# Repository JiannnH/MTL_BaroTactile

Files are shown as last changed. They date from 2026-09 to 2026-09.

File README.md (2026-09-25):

# MTL_BaroTactile

**A cost-efficient, repairable barometric tactile sensor**





<p align="center">
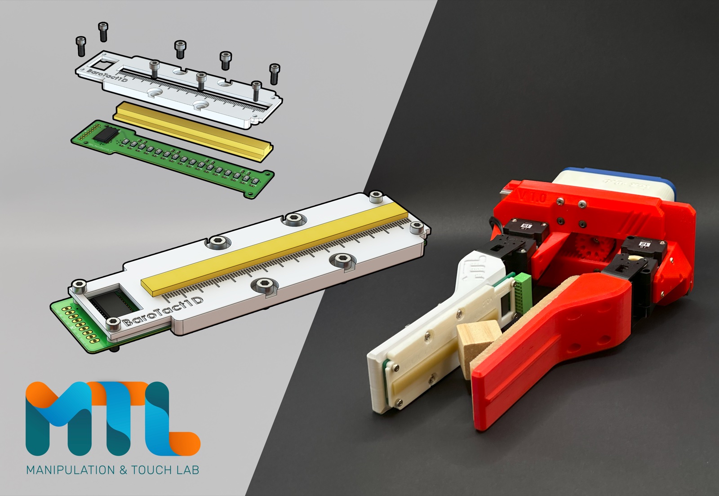
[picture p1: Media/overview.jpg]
BaroTact1D sensor exploded view and the sensor mounted on the E-TRoll gripper
  
</p>

## Highlights

- **Low cost:** material cost below **80 USD**, built from 16 MPL3115A2 MEMS barometers on a single PCB.
- **Repairable:** the rubber layer is molded **separately** rather than over the barometers, then clamped on by a 3D-printed frame, so a worn surface can be swapped in minutes.

## Sensor Design

<p align="center">
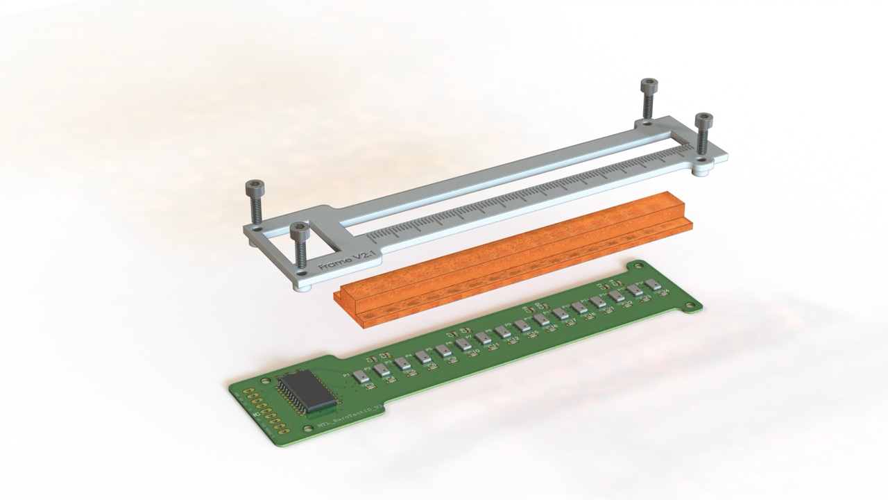
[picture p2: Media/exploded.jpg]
Exploded view: frame, rubber, PCB
  
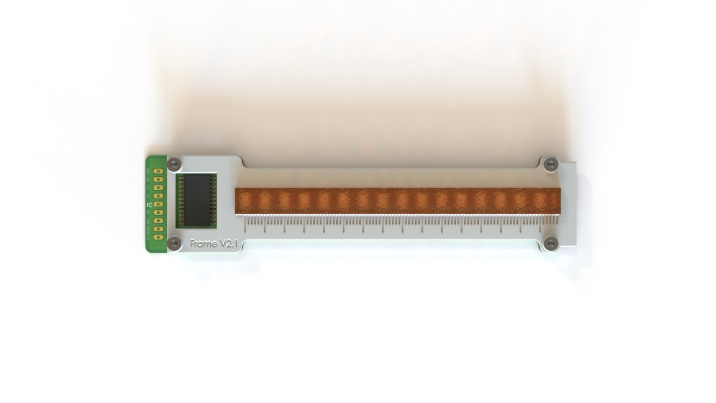
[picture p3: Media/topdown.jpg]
Top-down view of the assembled sensor
  
</p>

The sensor has three layers:

1. **PCB**: 16 MPL3115A2 barometers in a 1D array, read through a multiplexer.
2. **Rubber**: a VytaFlex 40 strip cast in a 3D-printed mold.
3. **Frame**: a 3D-printed clamp bolted to the PCB that holds the rubber in place.

## Demo: Real-Time Localization on the E-TRoll Gripper

<p align="center">
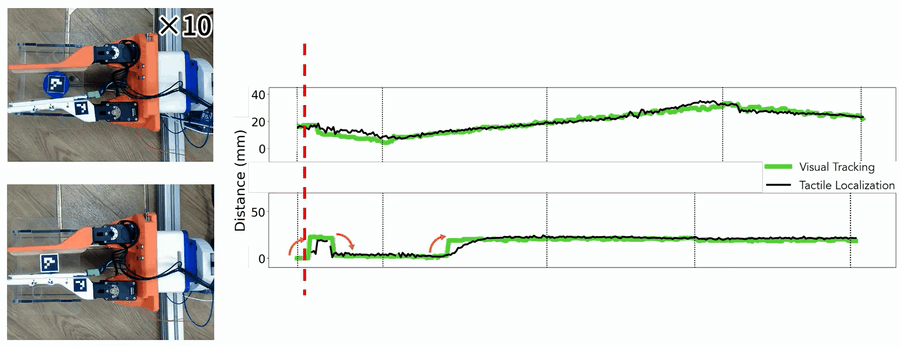
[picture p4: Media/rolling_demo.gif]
Real-time rolling experiment: tactile localization vs visual tracking
  
</p>

The sensor is mounted on one finger of the open-source
[**E-TRoll gripper**](https://www.imperial.ac.uk/manipulation-touch/open-source/hardware/e-troll/)
from the Manipulation and Touch Lab. The gripper rolls a cube and a cylinder across the
sensing surface, and the tactile estimate (black) closely tracks the camera-based ground truth (green).
The video plays at 10× speed.

## Repository Structure

- **[Code](Code/)**: Arduino code for the sensor (MPL3115A2) and the testing rig
- **[Hardware](Hardware/)**: PCB designs, 3D CAD files and testing rig hardware
  - **[PCB/MTL_BaroTactile_MPL3115A2](Hardware/PCB/MTL_BaroTactile_MPL3115A2/)**: main sensor version (used in the paper)
  - **[PCB/MTL_BaroTactile_MS5840](Hardware/PCB/MTL_BaroTactile_MS5840/)**: alternative version with the MS5840
  - **[Mold](Hardware/Mold/)**: rubber mold and frame CAD for fabrication
  - **[TestingRig](Hardware/TestingRig/)**: automated indentation rig for data collection

## Hardware Versions

### MPL3115A2 Version (Paper Implementation)
The primary sensor design, built with the MPL3115A2 barometric pressure sensor.

### MS5840 Version (Alternative)
An alternative design built with the MS5840 barometer. Use it when the MPL3115A2 is out of stock; it gives comparable performance for barometric tactile sensing.

## Fabrication Overview

1. 3D print the rubber mold and apply mold release spray.
2. Mix parts A and B of Smooth-On VytaFlex 40, de-gas the mixture, and pour it into the mold.
3. Close the mold and let it cure for at least 1 day, then remove the rubber.
4. Reflow-solder the components onto the PCB.
5. Place the rubber on the PCB, then bolt the 3D-printed frame over it until the rubber is held securely.

## Citation

If you use this work in your research, please cite our paper:

```bibtex
@ARTICLE{10770605,
  author={Hou, Jian and Zhou, Xin and Spiers, Adam},
  journal={IEEE Transactions on Robotics},
  title={Location and Orientation Super-Resolution Sensing With a Cost-Efficient and Repairable Barometric Tactile Sensor},
  year={2025},
  volume={41},
  pages={729-741},
  doi={10.1109/TRO.2024.3508315}
}
```

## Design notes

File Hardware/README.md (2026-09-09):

# Hardware Design

This folder contains the hardware design files.

## Folder Structure

The repository is organized into the following folders:

**PCB Design**: This folder contains schematics and layout files for our PCB. *PCB/MTL_BaroTactile_MPL3115A2/MTL_BaroTact1D_V3* is the one we used for super-resolution. *PCB/MTL_BaroTactile_MS5840/MTL_BaroTact1D_V4* is a new PCB design, which uses the MS-5840 barometer instead of the MPL3115A2 (stopped manufacturing).
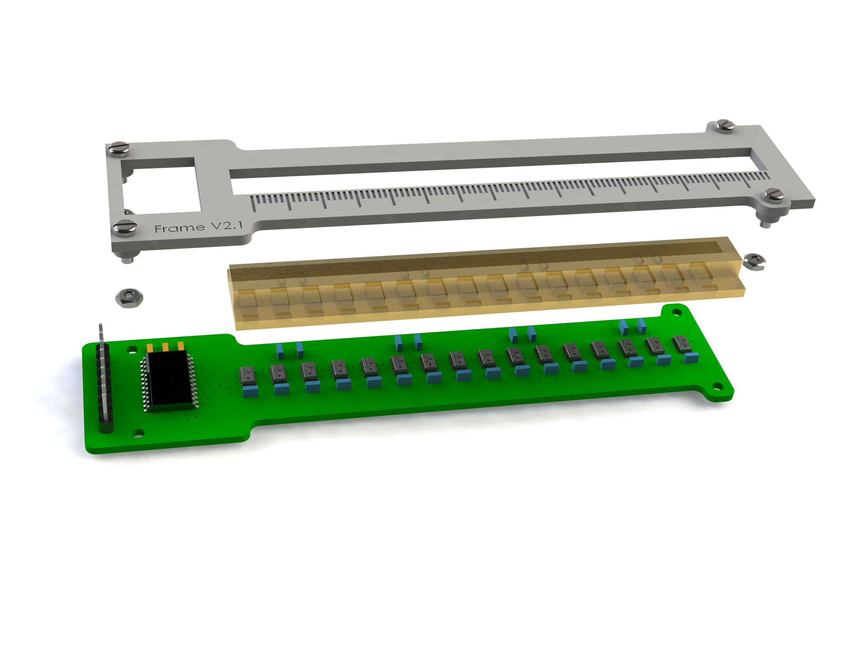
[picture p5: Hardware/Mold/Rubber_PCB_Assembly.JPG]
Sensor Design


**Testing Rig Design**: In this folder, you'll find the 3D-printed components on our testing rig.
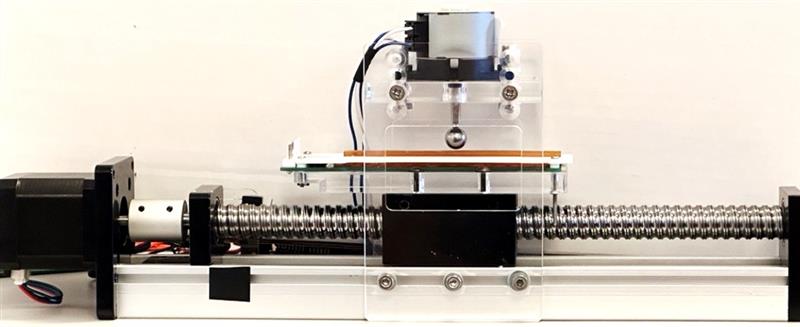
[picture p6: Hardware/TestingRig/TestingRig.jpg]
Testing Rig


**Mold**: This folder contains CAD files related to the mold used in the manufacturing process and assembly method of rubber components and sensors within our hardware.
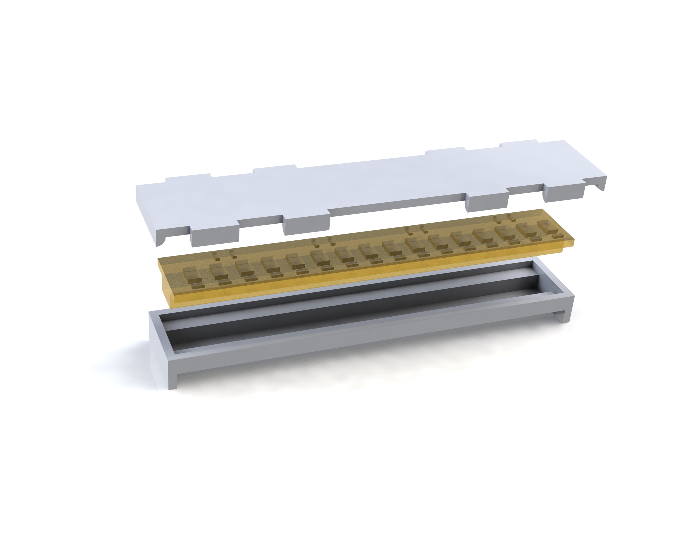
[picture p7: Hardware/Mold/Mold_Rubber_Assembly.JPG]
Mold


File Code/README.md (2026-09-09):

# Firmware

This folder contains the Firmware code for Testing Rig and the Barometric Tactile Sensor.

## Folder Structure

The repository is organized into the following folders:

**Testing_Rig**: Contains the Arduino firmware code for controlling the Testing Rig used in data collection.

**Sensor**: Contains the Arduino firmware code for the Barometric Tactile Sensor, receiving the real-time input for 16 barometers' reading.

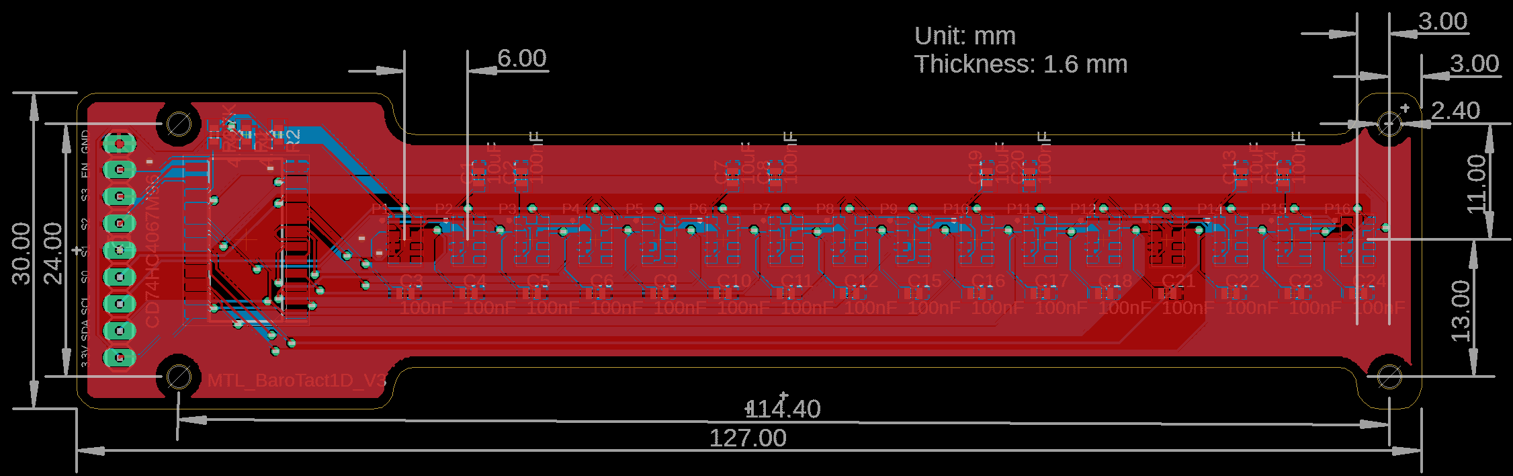
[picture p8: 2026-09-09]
Hardware/PCB/MTL_BaroTactile_MPL3115A2/MTL_BaroTact1D_V3/1D_layout.png

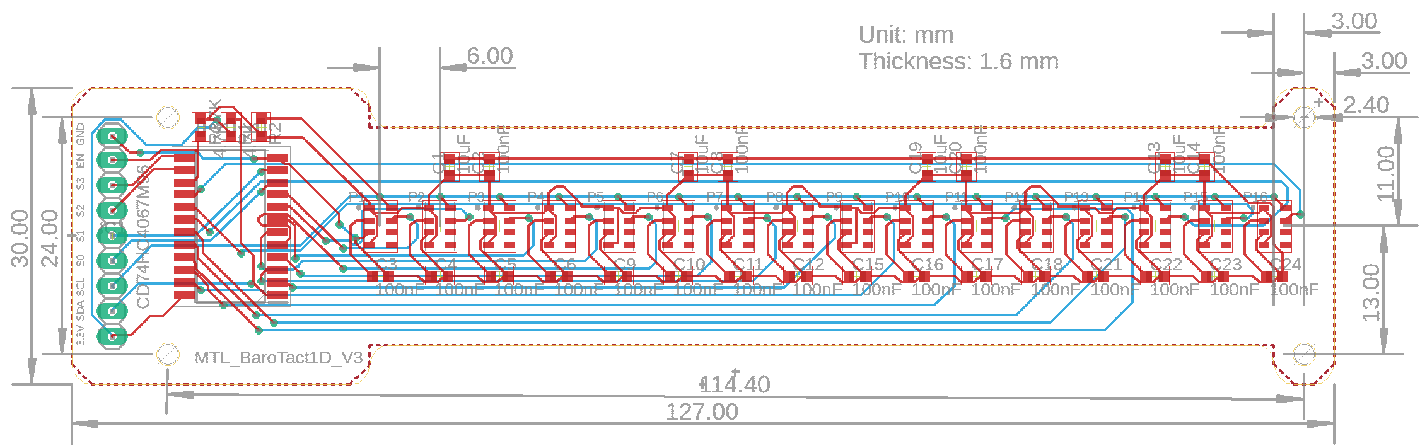
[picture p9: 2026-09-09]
Hardware/PCB/MTL_BaroTactile_MPL3115A2/MTL_BaroTact1D_V3/1D_layout_white.png

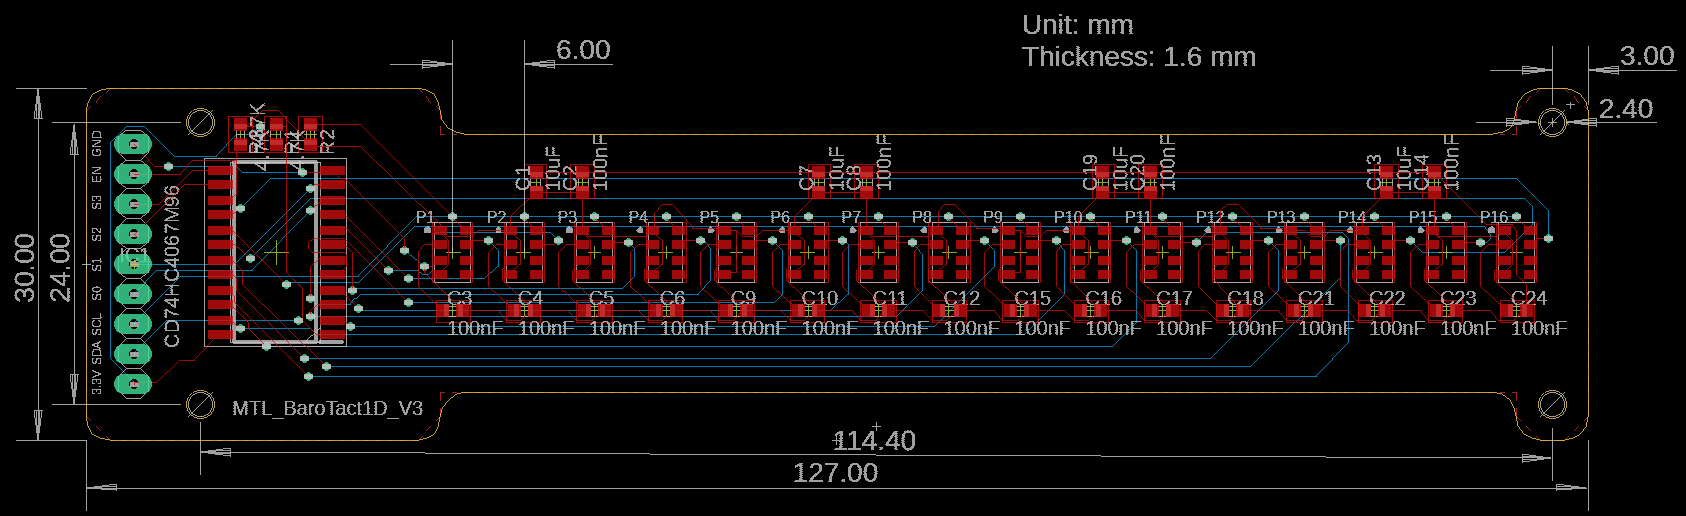
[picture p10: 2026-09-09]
Hardware/PCB/MTL_BaroTactile_MPL3115A2/MTL_BaroTact1D_V3/MTL_Barotact1D_V3.png

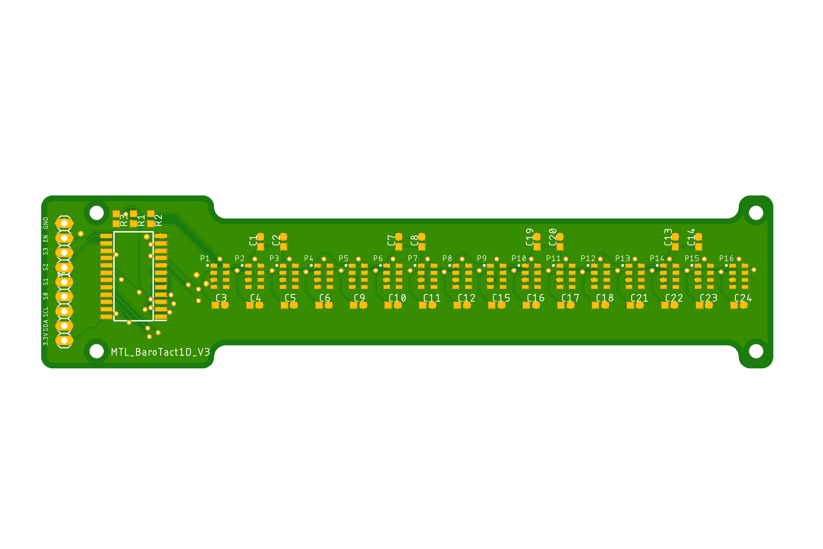
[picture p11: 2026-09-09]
Hardware/PCB/MTL_BaroTactile_MPL3115A2/MTL_BaroTact1D_V3/1D_layout_3D.png

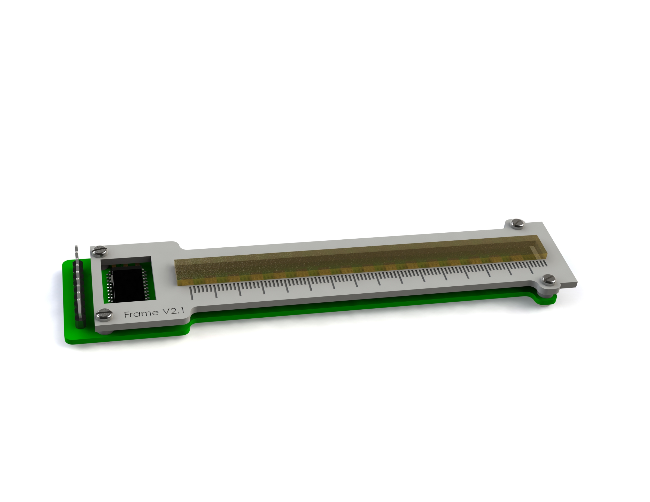
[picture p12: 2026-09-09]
Hardware/Mold/Rubber_PCB_Explode.JPG

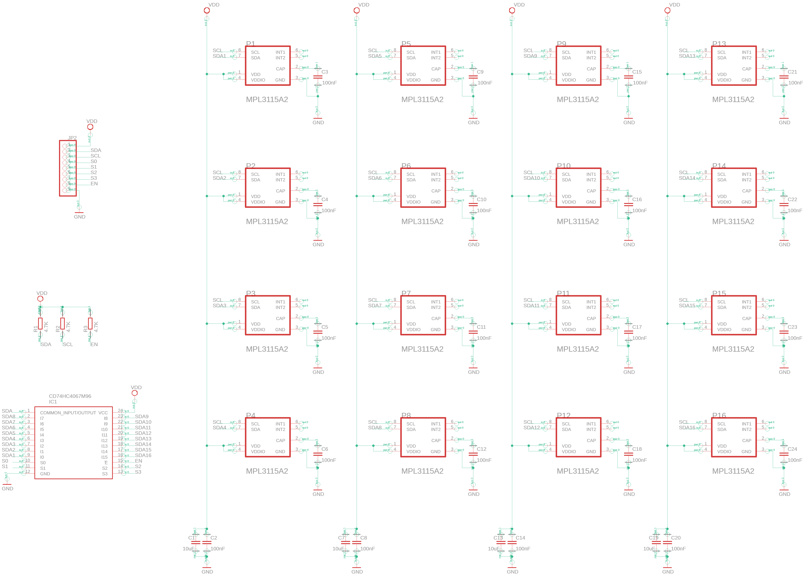
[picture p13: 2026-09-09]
Hardware/PCB/MTL_BaroTactile_MPL3115A2/1D_Sche_img.png

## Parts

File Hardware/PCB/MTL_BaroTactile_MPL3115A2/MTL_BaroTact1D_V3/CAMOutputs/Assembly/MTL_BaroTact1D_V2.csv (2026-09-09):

 |  |  | 1D
Qty | Name | Price(?) | Link | Min order Qty | Note
1 | PINHD-1X9 | 0.647 | https://uk.rs-online.com/web/p/pcb-headers/0453224 | 10 |  | 0.647
1 | CD74HC4067M96 | 0.855 | https://uk.rs-online.com/web/p/multiplexer-demultiplexer-ics/6622577 | 10 |  | 0.855
16 | MPL3115A2 | 8.54 | https://uk.rs-online.com/web/p/pressure-sensor-ics/7500841 | 1 | If ordering 490 pieces or more, the price is ?4.785 | 136.64
1 | 4.7K RR0603 | 0.022 | https://uk.rs-online.com/web/p/thermistor-ics/0110510 | 25 |  | 0.022
1 | 10uF CC0603 | 0.243 | https://uk.rs-online.com/web/p/mlccs-multilayer-ceramic-capacitors/8151377 | 25 |  | 0.243
1 | 100nF CC0603 | 0.243 | https://uk.rs-online.com/web/p/mlccs-multilayer-ceramic-capacitors/8151377 | 25 |  | 0.243
 | Est Price/set | 138.65
 |  |  | 2D
Qty | Name | Price(?) | Link | Min order Qty | Note
1 | PINHD-1X9 | 0.647 | https://uk.rs-online.com/web/p/pcb-headers/0453224 | 10 |  | 0.647
1 | CD74HC4067M96 | 0.855 | https://uk.rs-online.com/web/p/multiplexer-demultiplexer-ics/6622577 | 10 |  | 0.855
16 | MPL3115A2 | 8.54 | https://uk.rs-online.com/web/p/pressure-sensor-ics/7500841 | 1 | If ordering 490 pieces or more, the price is ?4.785 | 136.64
1 | 4.7K RR0603 | 0.022 | https://uk.rs-online.com/web/p/thermistor-ics/0110510 | 25 |  | 0.022
1 | 10uF CC0402 | 0.131 | https://uk.rs-online.com/web/p/mlccs-multilayer-ceramic-capacitors/8467271 | 25 |  | 0.131
1 | 100nF CC0402 | 0.041 | https://uk.rs-online.com/web/p/mlccs-multilayer-ceramic-capacitors/1034089 | 50 |  | 0.041
 | Est Price/set | 138.336

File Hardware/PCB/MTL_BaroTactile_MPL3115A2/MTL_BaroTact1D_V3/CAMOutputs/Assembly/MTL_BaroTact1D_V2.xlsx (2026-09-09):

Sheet: MTL_BaroTact1D_V2
Qty;"Value";"Device";"Package";"Parts";"Description";"CIIVA_IDS";"COMPONENT_LINK_1_DESCRIPTION";"COMPONENT_LINK_1_URL";"COMPONENT_LINK_3_DESCRIPTION";"COMPONENT_LINK_3_URL";"DATASHEET";"DATASHEET_VERSION";"DESCRIPTION";"FOOTPRINT_VARIANT_NAME_0";"FSCL20_PF";"FSCL400_PF";"HEIGHT";"IMPORTED";"IMPORTED_FROM";"IMPORT_TS";"MANUFACTURER_NAME";"MANUFACTURER_PART_NUMBER";"MF";"MOUNTING_TECHNOLOGY";"MOUSER_PART_NUMBER";"MOUSER_PRICE-STOCK";"MPN";"OPERATING_TEMPERATURE_RANGE";"PACKAGE_DESCRIPTION";"PACKAGE_VERSION";"PACKING";"PIN_0_0_7_INSIDE_EDGE";"POPULARITY";"PREFIX";"RELEASE_DATE";"ROHS";"SPICEMODEL";"SPICEPREFIX";"VAULT_GUID";"VAULT_REVISION";"VDD";"VDDIO";
1;"";"PINHD-1X9";"1X09";"JP2";"PIN HEADER";"";"";"";"";"";"";"";"";"";"";"";"";"";"";"";"";"";"";"";"";"";"";"";"";"";"";"";"13";"";"";"";"";"";"";"";"";"";
20;"100nF";"CC0603";"C0603";"C2 | C3 | C4 | C5 | C6 | C8 | C9 | C10 | C11 | C12 | C14 | C15 | C16 | C17 | C18 | C20 | C21 | C22 | C23 | C24";"CAPACITOR | European symbol";"";"";"";"";"";"";"";"";"";"";"";"";"";"";"";"";"";"";"";"";"";"";"";"";"";"";"";"";"";"";"";"NONE";"C";"";"";"";"";
4;"10uF";"CC0603";"C0603";"C1 | C7 | C13 | C19";"CAPACITOR | European symbol";"";"";"";"";"";"";"";"";"";"";"";"";"";"";"";"";"";"";"";"";"";"";"";"";"";"";"";"";"";"";"";"NONE";"C";"";"";"";"";
3;"4.7K";"RR0603";"R0603";"R1 | R2 | R3";"RESISTOR | European symbol";"";"";"";"";"";"";"";"";"";"";"";"";"";"";"";"";"";"";"";"";"";"";"";"";"";"";"";"";"";"";"";"NONE";"R";"";"";"";"";
1;"CD74HC4067M96";"CD74HC4067M96";"SOIC127P1030X265-24N";"IC1";"High Speed CMOS 16-Channel Analog Multiplexer/Demultiplexer";"";"";"";"";"";"";"";"High Speed CMOS 16-Channel Analog Multiplexer/Demultiplexer";"";"";"";"2.65mm";"";"";"";"Texas Instruments";"CD74HC4067M96";"";"";"595-CD74HC4067M96";"https://www.mouser.co.uk/ProductDetail/Texas-Instruments/CD74HC4067M96?qs=xFfolx0DHx0XT7d9xTTZBA%3D%3D";"";"";"";"";"";"";"";"";"";"";"";"";"";"";"";"";
16;"FREESCALE_SEMICONDUCTOR_MPL3115A2FREESCALE_SEMICONDUCTOR_MPL3115A2_0_0";"FREESCALE_SEMICONDUCTOR_MPL3115A2FREESCALE_SEMICONDUCTOR_MPL3115A2_0_0";"FREESCALE_SEMICONDUCTOR_MPL3115A2_0";"P1 | P2 | P3 | P4 | P5 | P6 | P7 | P8 | P9 | P10 | P11 | P12 | P13 | P14 | P15 | P16";"FRES-MPL3115A2-8";"1172243";"Manufacturer URL";"http://www.freescale.com/";"Package Specification";"http://cache.freescale.com/files/shared/doc/package_info/98ASA00260D.pdf";"http://cache.freescale.com/files/sensors/doc/data_sheet/MPL3115A2.pdf";"Rev. 3.0";"";"Manufacturer Recommended";"4 MHz Max.";"400 KHz Max.";"";"yes";"vault";"1521845373";"";"";"Freescale Semiconductor";"Surface Mount";"";"";"MPL3115A2";"-40 to 85 degC";"8-Pin Land Grid Array | Body 5 x 3 mm | Pitch 1.25 mm";"Rev. O";"Tray";"clock";"";"U";"1435138815";"Yes";"";"";"C9CA789F-172F-4FBE-A7EA-5C936E43DE32";"13F1D4E8-B129-4F1C-B772-6A98733F3276";"1.95 to 3.6 V";"1.62 to 3.6 V";

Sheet: Sheet1
1D
Qty | Name | Price(£) | Link | Min order Qty | Note
1 | PINHD-1X9 | 0.647 | https://uk.rs-online.com/web/p/pcb-headers/0453224 | 10 |  | 0.647
1 | Nexperia HEF4067BT | 1.93 | https://uk.rs-online.com/web/p/multiplexer-demultiplexer-ics/0788817 | 1 |  | 1.93
1 | CD74HC4067M96 | 0.855 | https://uk.rs-online.com/web/p/multiplexer-demultiplexer-ics/6622577 | 10 | Currently out of stock | 0.855
16 | MPL3115A2 | 8.54 | https://uk.rs-online.com/web/p/pressure-sensor-ics/7500841 | 1 | If ordering 490 pieces or more, the price is £4.785 | 136.64
3 | 4.7K RR0603 | 0.022 | https://uk.rs-online.com/web/p/thermistor-ics/0110510 | 25 |  | 0.066 | 71-CRCW0603J-4.7K-E3
4 | 10uF CC0603 | 0.243 | https://uk.rs-online.com/web/p/mlccs-multilayer-ceramic-capacitors/8151377 | 25 |  | 0.972 | 581-0603ZW106MAT2A
20 | 100nF CC0603 | 0.243 | https://uk.rs-online.com/web/p/mlccs-multilayer-ceramic-capacitors/8151377 | 25 |  | 4.86 | 581-0603YC104J4T4A
 | Est Price/set | 145.115
2D
Qty | Name | Price(£) | Link | Min order Qty | Note
1 | PINHD-1X9 | 0.647 | https://uk.rs-online.com/web/p/pcb-headers/0453224 | 10 |  | 0.647
1 | Nexperia HEF4067BT | 1.93 | https://uk.rs-online.com/web/p/multiplexer-demultiplexer-ics/0788817 | 1 |  | 1.93
1 | CD74HC4067M96 | 0.855 | https://uk.rs-online.com/web/p/multiplexer-demultiplexer-ics/6622577 | 10 | Currently out of stock | 0.855
16 | MPL3115A2 | 8.54 | https://uk.rs-online.com/web/p/pressure-sensor-ics/7500841 | 1 | If ordering 490 pieces or more, the price is £4.785 | 136.64
3 | 4.7K RR0603 | 0.022 | https://uk.rs-online.com/web/p/thermistor-ics/0110510 | 25 |  | 0.066 | 71-CRCW0603J-4.7K-E3
4 | 10uF CC0402 | 0.131 | https://uk.rs-online.com/web/p/mlccs-multilayer-ceramic-capacitors/8467271 | 25 |  | 0.524 | 581-0402ZD106MAT2A
20 | 100nF CC0402 | 0.041 | https://uk.rs-online.com/web/p/mlccs-multilayer-ceramic-capacitors/1034089 | 50 |  | 0.82 | 581-04023C104KAT2A
 | Est Price/set | 140.627

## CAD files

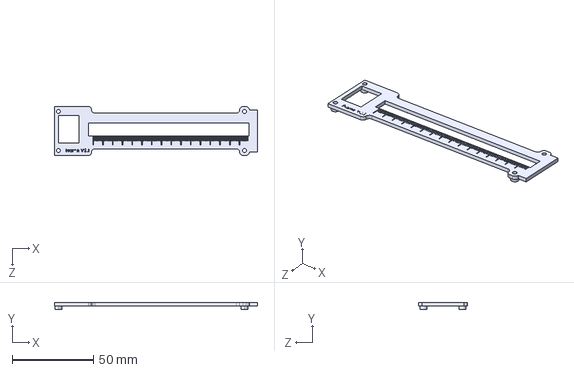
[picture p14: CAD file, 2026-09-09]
Hardware/Mold/frame.STEP
124.8 x 4.00 x 30.0 mm

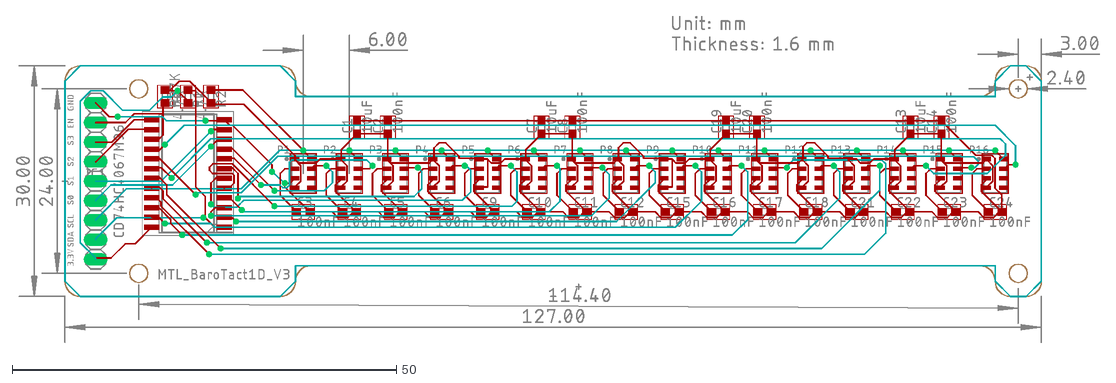
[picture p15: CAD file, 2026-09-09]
Hardware/PCB/MTL_BaroTactile_MPL3115A2/MTL_BaroTact1D_V3/MTL_BaroTact1D_V3.dxf
141.0 x 42.5

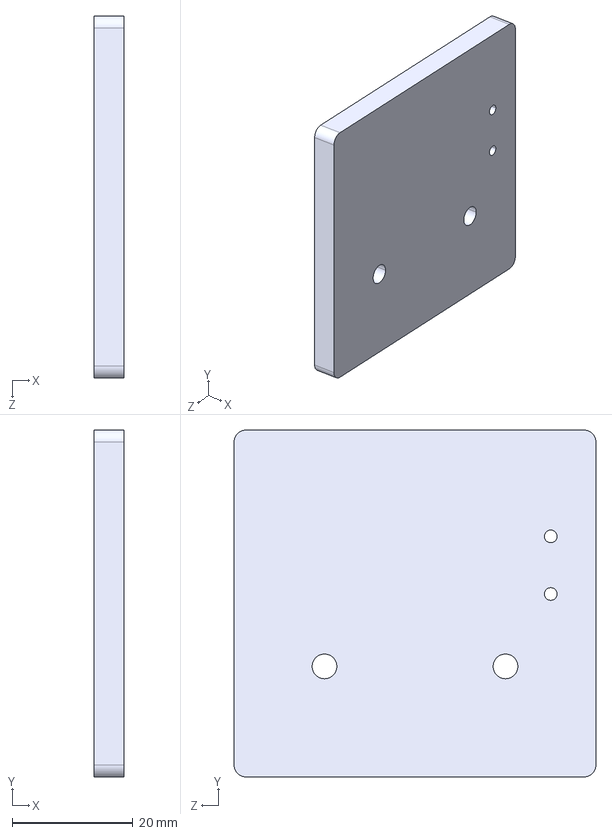
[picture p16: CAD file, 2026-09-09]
Hardware/TestingRig/LimitSwitchMount_V1.STEP
5.00 x 57.5 x 60.0 mm

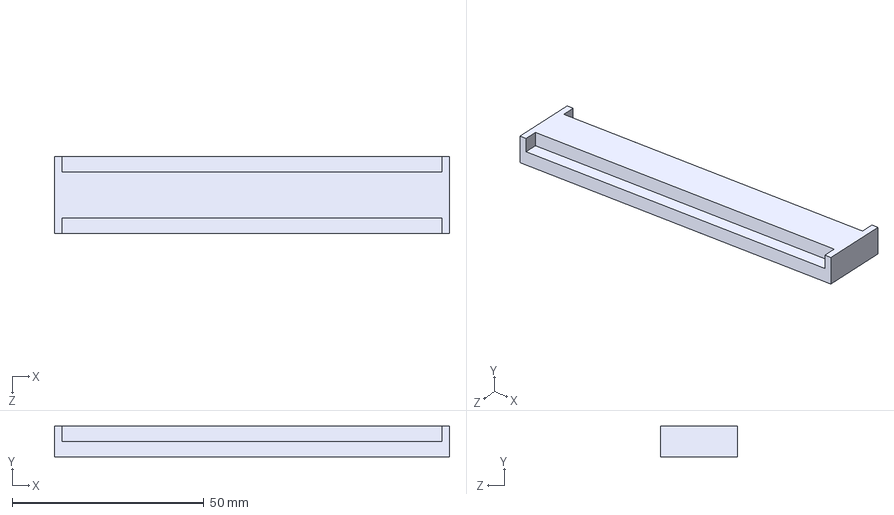
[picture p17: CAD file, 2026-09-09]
Hardware/Mold/mold_base.STEP
103.0 x 8.00 x 20.0 mm

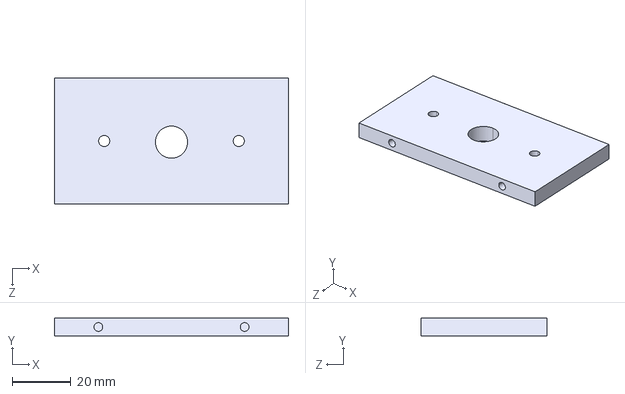
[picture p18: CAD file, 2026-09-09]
Hardware/TestingRig/Cross Bracket V1.STEP
80.0 x 6.00 x 43.0 mm

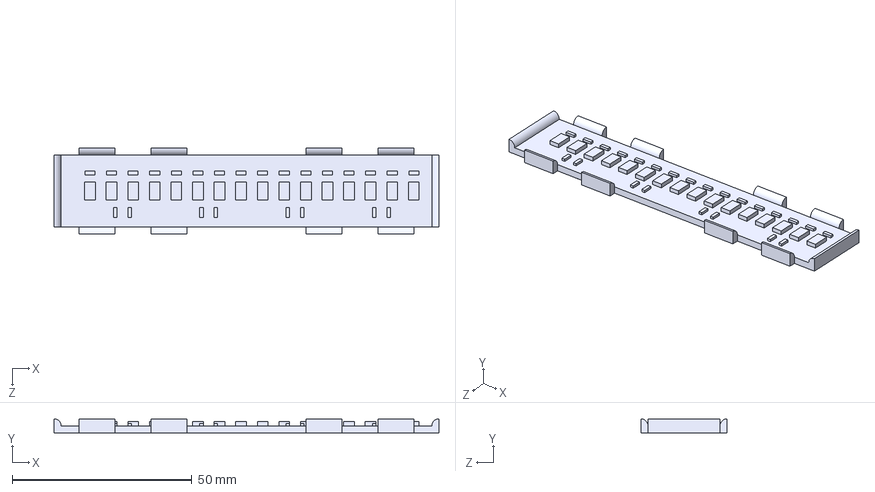
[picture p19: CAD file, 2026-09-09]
Hardware/Mold/mold_top.STEP
107.0 x 4.00 x 24.0 mm

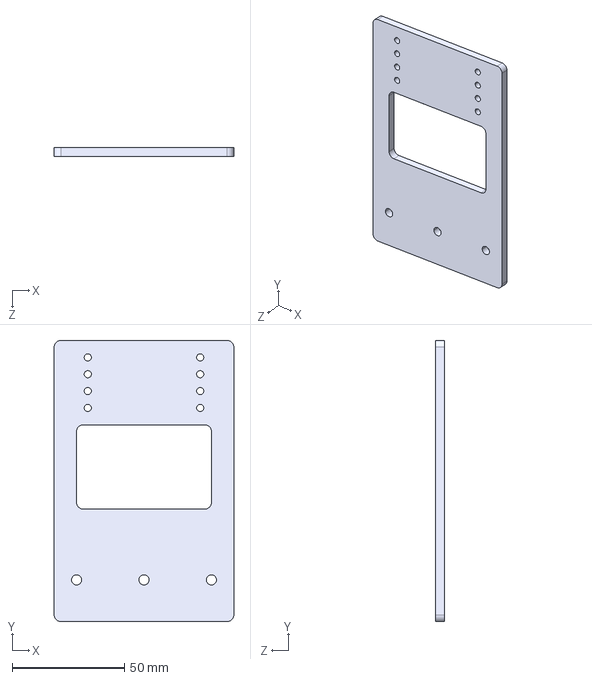
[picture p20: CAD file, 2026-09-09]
Hardware/TestingRig/Z Actuator upright panel V1.STEP
80.0 x 125.0 x 4.00 mm

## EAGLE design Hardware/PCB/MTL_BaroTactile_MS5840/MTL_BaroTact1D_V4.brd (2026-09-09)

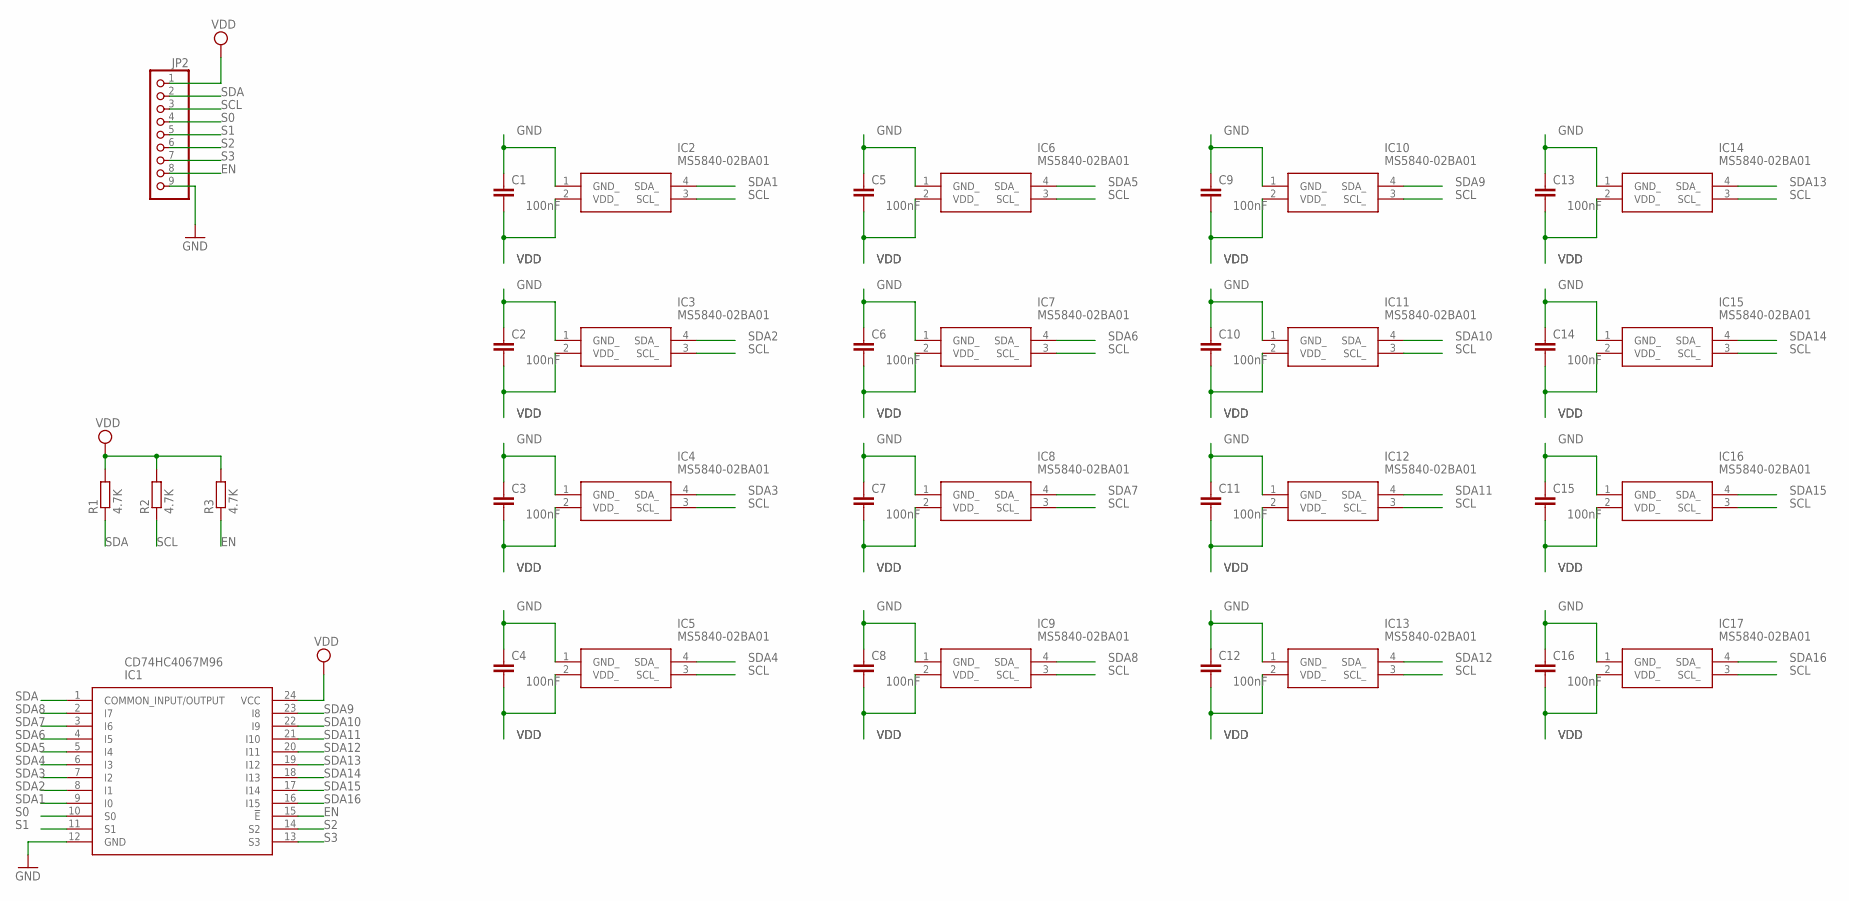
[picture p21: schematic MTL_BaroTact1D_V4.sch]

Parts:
C1, C2, C3, C4, C5, C6, C7, C8, C9, C10, C11, C12, C13, C14, C15, C16: 100nF; C0603
IC1: CD74HC4067M96; SOIC127P1030X265-24N
IC2, IC3, IC4, IC5, IC6, IC7, IC8, IC9, IC10, IC11, IC12, IC13, IC14, IC15, IC16, IC17: MS5840-02BA01; MS584002BA01
JP2: PINHD-1X9; 1X09
R1, R2, R3: 4.7K; R0603

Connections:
EN: IC1.15 (!E), JP2.8, R3.1
GND: C1.1, C2.1, C3.1, C4.1, C5.1, C6.1, C7.1, C8.1, C9.1, C10.1, C11.1, C12.1, C13.1, C14.1, C15.1, C16.1, IC1.12 (GND), IC2.1 (GND_), IC3.1 (GND_), IC4.1 (GND_), IC5.1 (GND_), IC6.1 (GND_), IC7.1 (GND_), IC8.1 (GND_), IC9.1 (GND_), IC10.1 (GND_), IC11.1 (GND_), IC12.1 (GND_), IC13.1 (GND_), IC14.1 (GND_), IC15.1 (GND_), IC16.1 (GND_), IC17.1 (GND_), JP2.9
S0: IC1.10 (S0), JP2.4
S1: IC1.11 (S1), JP2.5
S2: IC1.14 (S2), JP2.6
S3: IC1.13 (S3), JP2.7
SCL: IC2.3 (SCL_), IC3.3 (SCL_), IC4.3 (SCL_), IC5.3 (SCL_), IC6.3 (SCL_), IC7.3 (SCL_), IC8.3 (SCL_), IC9.3 (SCL_), IC10.3 (SCL_), IC11.3 (SCL_), IC12.3 (SCL_), IC13.3 (SCL_), IC14.3 (SCL_), IC15.3 (SCL_), IC16.3 (SCL_), IC17.3 (SCL_), JP2.3, R2.1
SDA: IC1.1 (COMMON_INPUT/OUTPUT), JP2.2, R1.1
SDA1: IC1.9 (I0), IC2.4 (SDA_)
SDA2: IC1.8 (I1), IC3.4 (SDA_)
SDA3: IC1.7 (I2), IC4.4 (SDA_)
SDA4: IC1.6 (I3), IC5.4 (SDA_)
SDA5: IC1.5 (I4), IC6.4 (SDA_)
SDA6: IC1.4 (I5), IC7.4 (SDA_)
SDA7: IC1.3 (I6), IC8.4 (SDA_)
SDA8: IC1.2 (I7), IC9.4 (SDA_)
SDA9: IC1.23 (I8), IC10.4 (SDA_)
SDA10: IC1.22 (I9), IC11.4 (SDA_)
SDA11: IC1.21 (I10), IC12.4 (SDA_)
SDA12: IC1.20 (I11), IC13.4 (SDA_)
SDA13: IC1.19 (I12), IC14.4 (SDA_)
SDA14: IC1.18 (I13), IC15.4 (SDA_)
SDA15: IC1.17 (I14), IC16.4 (SDA_)
SDA16: IC1.16 (I15), IC17.4 (SDA_)
VDD: C1.2, C2.2, C3.2, C4.2, C5.2, C6.2, C7.2, C8.2, C9.2, C10.2, C11.2, C12.2, C13.2, C14.2, C15.2, C16.2, IC1.24 (VCC), IC2.2 (VDD_), IC3.2 (VDD_), IC4.2 (VDD_), IC5.2 (VDD_), IC6.2 (VDD_), IC7.2 (VDD_), IC8.2 (VDD_), IC9.2 (VDD_), IC10.2 (VDD_), IC11.2 (VDD_), IC12.2 (VDD_), IC13.2 (VDD_), IC14.2 (VDD_), IC15.2 (VDD_), IC16.2 (VDD_), IC17.2 (VDD_), JP2.1, R1.2, R2.2, R3.2

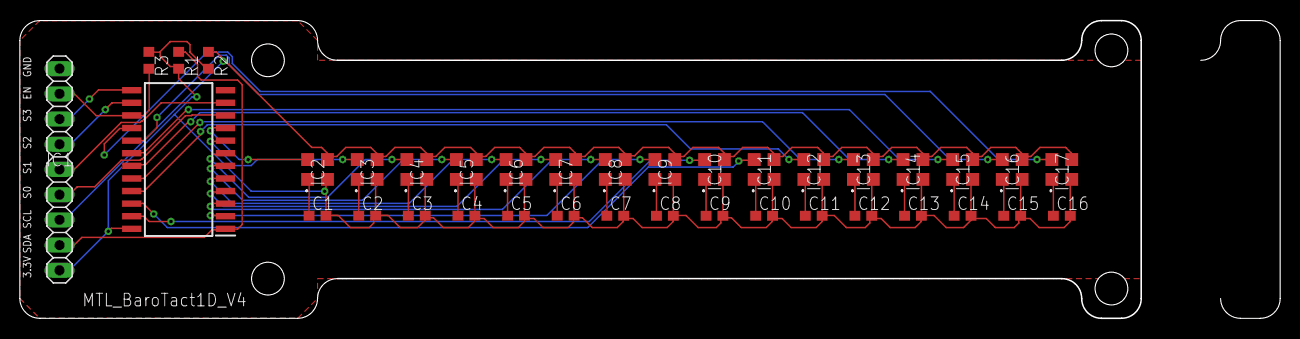
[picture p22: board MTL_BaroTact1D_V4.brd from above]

Board: 2 copper layers, 113.0 x 30.0 mm, 37 parts (0 on the bottom side), 25 nets.

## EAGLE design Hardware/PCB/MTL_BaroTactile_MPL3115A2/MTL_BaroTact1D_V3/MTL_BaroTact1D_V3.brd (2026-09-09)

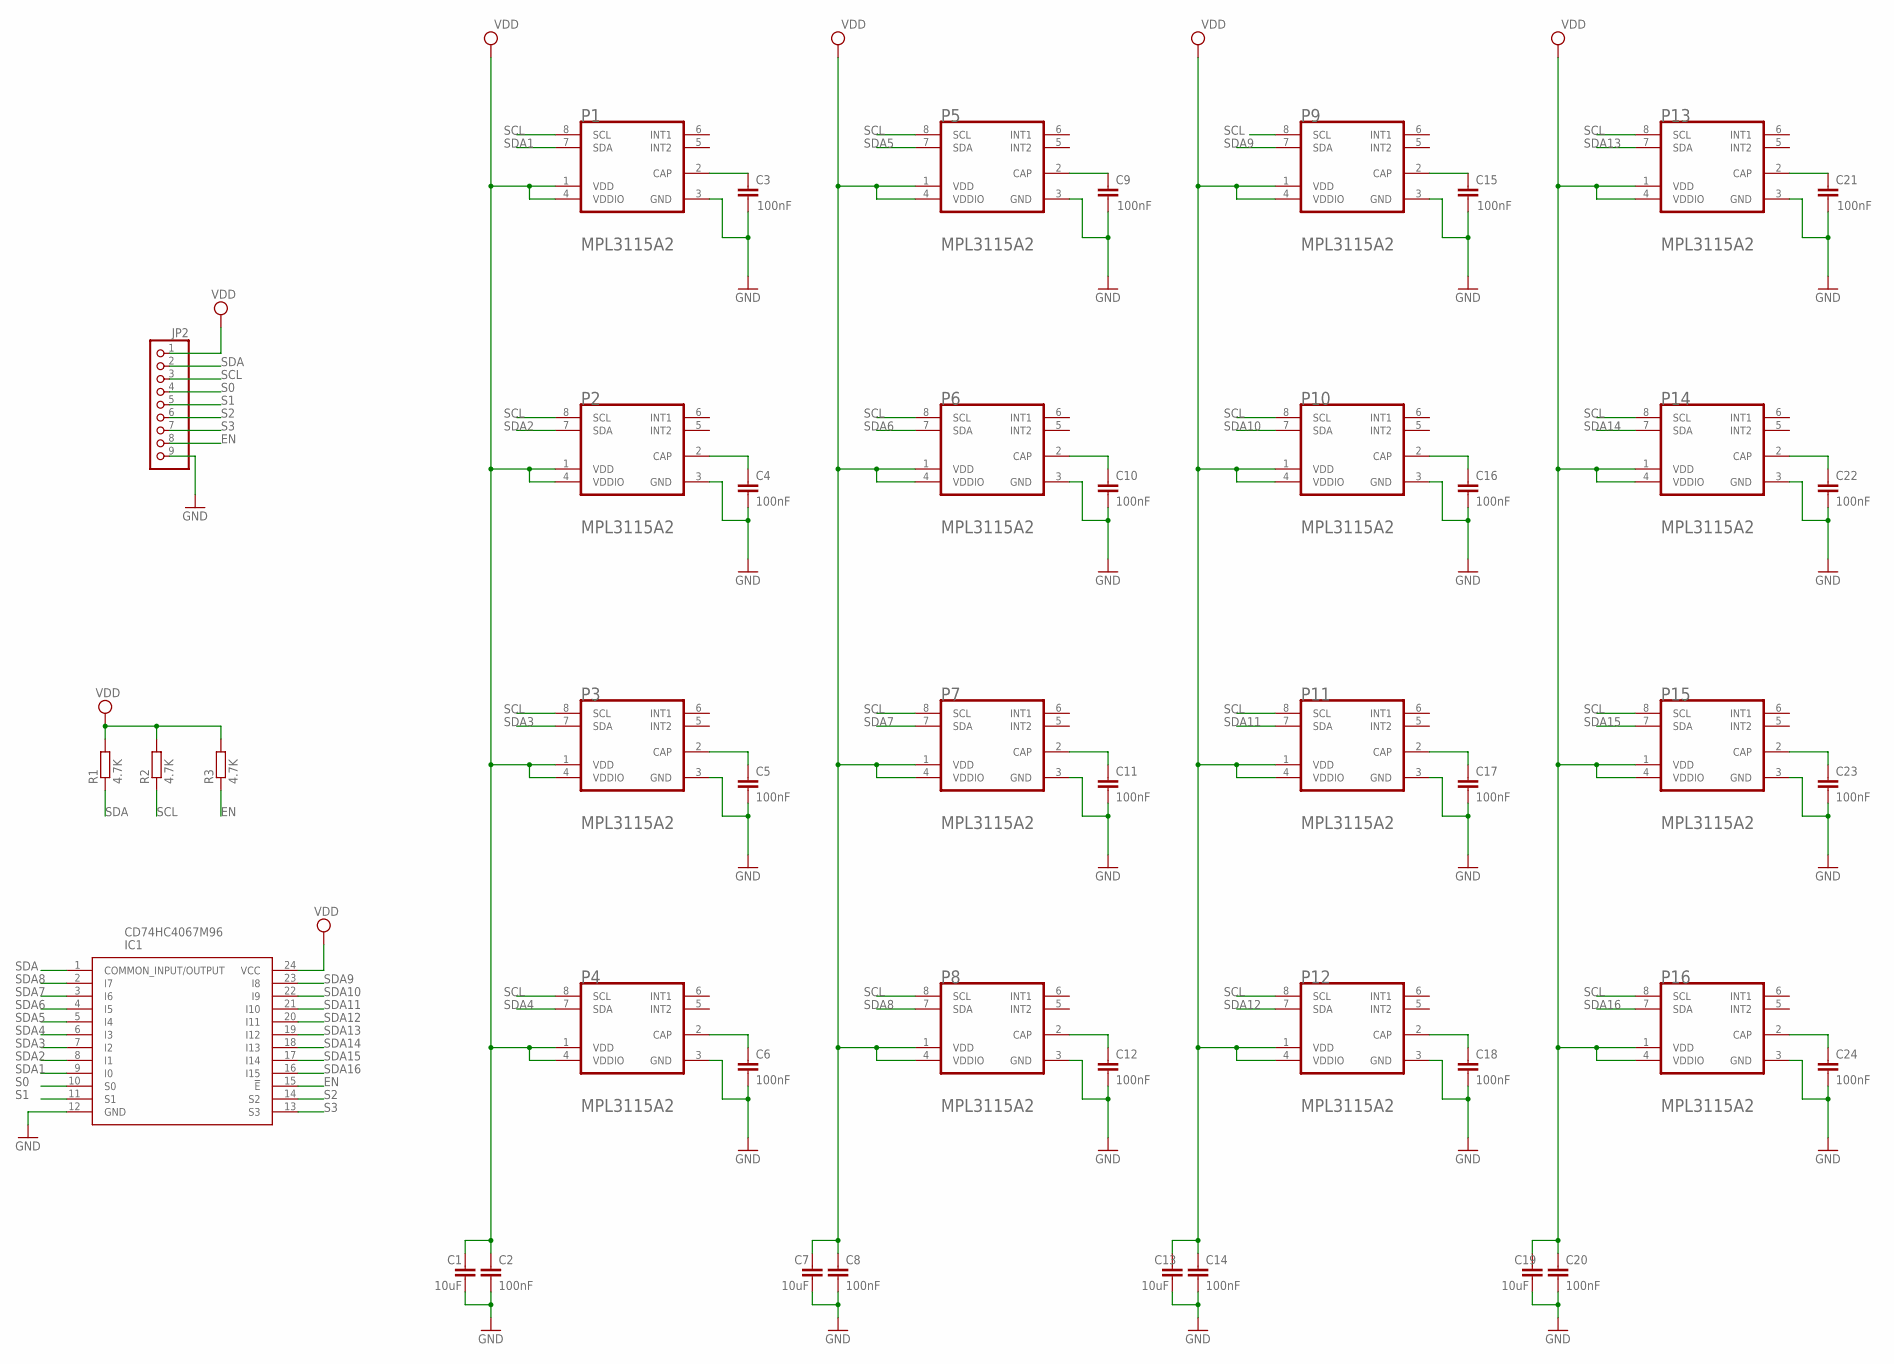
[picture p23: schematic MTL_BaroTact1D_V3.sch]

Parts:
C1, C7, C13, C19: 10uF; C0603
C2, C3, C4, C5, C6, C8, C9, C10, C11, C12, C14, C15, C16, C17, C18, C20, C21, C22, C23, C24: 100nF; C0603
IC1: CD74HC4067M96; SOIC127P1030X265-24N
JP2: PINHD-1X9; 1X09
P1, P2, P3, P4, P5, P6, P7, P8, P9, P10, P11, P12, P13, P14, P15, P16: FREESCALE_SEMICONDUCTOR_MPL3115A2FREESCALE_SEMICO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; FREESCALE_SEMICONDUCTOR_MPL3115A2_0
R1, R2, R3: 4.7K; R0603

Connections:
EN: IC1.15 (!E), JP2.8, R3.1
GND: C1.2, C2.2, C3.2, C4.2, C5.2, C6.2, C7.2, C8.2, C9.2, C10.2, C11.2, C12.2, C13.2, C14.2, C15.2, C16.2, C17.2, C18.2, C19.2, C20.2, C21.2, C22.2, C23.2, C24.2, IC1.12 (GND), JP2.9, P1.3 (GND), P2.3 (GND), P3.3 (GND), P4.3 (GND), P5.3 (GND), P6.3 (GND), P7.3 (GND), P8.3 (GND), P9.3 (GND), P10.3 (GND), P11.3 (GND), P12.3 (GND), P13.3 (GND), P14.3 (GND), P15.3 (GND), P16.3 (GND)
unnamed: C3.1, P1.2 (CAP)
unnamed: C4.1, P2.2 (CAP)
unnamed: C9.1, P5.2 (CAP)
unnamed: C10.1, P6.2 (CAP)
unnamed: C11.1, P7.2 (CAP)
unnamed: C12.1, P8.2 (CAP)
unnamed: C5.1, P3.2 (CAP)
unnamed: C6.1, P4.2 (CAP)
unnamed: C15.1, P9.2 (CAP)
unnamed: C16.1, P10.2 (CAP)
unnamed: C17.1, P11.2 (CAP)
unnamed: C18.1, P12.2 (CAP)
unnamed: C21.1, P13.2 (CAP)
unnamed: C22.1, P14.2 (CAP)
unnamed: C23.1, P15.2 (CAP)
unnamed: C24.1, P16.2 (CAP)
S0: IC1.10 (S0), JP2.4
S1: IC1.11 (S1), JP2.5
S2: IC1.14 (S2), JP2.6
S3: IC1.13 (S3), JP2.7
SCL: JP2.3, P1.8 (SCL), P2.8 (SCL), P3.8 (SCL), P4.8 (SCL), P5.8 (SCL), P6.8 (SCL), P7.8 (SCL), P8.8 (SCL), P9.8 (SCL), P10.8 (SCL), P11.8 (SCL), P12.8 (SCL), P13.8 (SCL), P14.8 (SCL), P15.8 (SCL), P16.8 (SCL), R2.1
SDA: IC1.1 (COMMON_INPUT/OUTPUT), JP2.2, R1.1
SDA1: IC1.9 (I0), P1.7 (SDA)
SDA2: IC1.8 (I1), P2.7 (SDA)
SDA3: IC1.7 (I2), P3.7 (SDA)
SDA4: IC1.6 (I3), P4.7 (SDA)
SDA5: IC1.5 (I4), P5.7 (SDA)
SDA6: IC1.4 (I5), P6.7 (SDA)
SDA7: IC1.3 (I6), P7.7 (SDA)
SDA8: IC1.2 (I7), P8.7 (SDA)
SDA9: IC1.23 (I8), P9.7 (SDA)
SDA10: IC1.22 (I9), P10.7 (SDA)
SDA11: IC1.21 (I10), P11.7 (SDA)
SDA12: IC1.20 (I11), P12.7 (SDA)
SDA13: IC1.19 (I12), P13.7 (SDA)
SDA14: IC1.18 (I13), P14.7 (SDA)
SDA15: IC1.17 (I14), P15.7 (SDA)
SDA16: IC1.16 (I15), P16.7 (SDA)
VDD: C1.1, C2.1, C7.1, C8.1, C13.1, C14.1, C19.1, C20.1, IC1.24 (VCC), JP2.1, P1.1 (VDD), P1.4 (VDDIO), P2.1 (VDD), P2.4 (VDDIO), P3.1 (VDD), P3.4 (VDDIO), P4.1 (VDD), P4.4 (VDDIO), P5.1 (VDD), P5.4 (VDDIO), P6.1 (VDD), P6.4 (VDDIO), P7.1 (VDD), P7.4 (VDDIO), P8.1 (VDD), P8.4 (VDDIO), P9.1 (VDD), P9.4 (VDDIO), P10.1 (VDD), P10.4 (VDDIO), P11.1 (VDD), P11.4 (VDDIO), P12.1 (VDD), P12.4 (VDDIO), P13.1 (VDD), P13.4 (VDDIO), P14.1 (VDD), P14.4 (VDDIO), P15.1 (VDD), P15.4 (VDDIO), P16.1 (VDD), P16.4 (VDDIO), R1.2, R2.2, R3.2

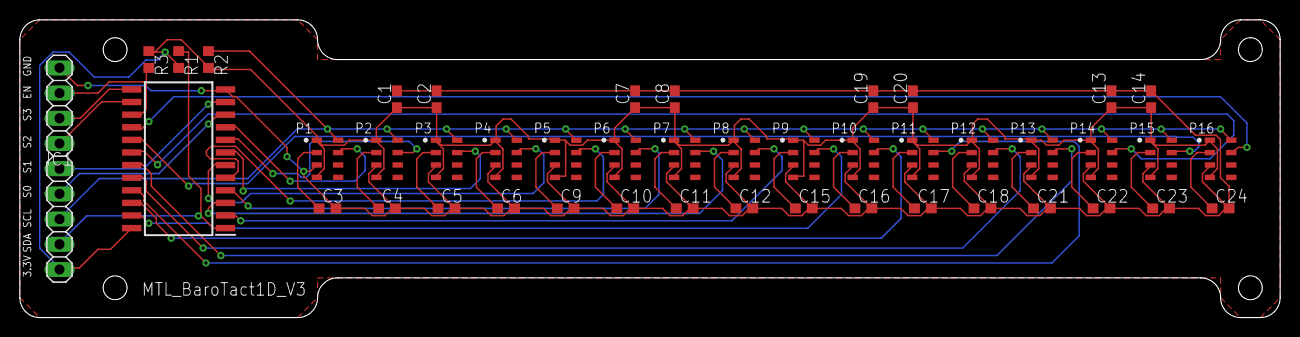
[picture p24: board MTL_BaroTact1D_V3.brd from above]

Board: 2 copper layers, 127.0 x 30.0 mm, 45 parts (0 on the bottom side), 41 nets.

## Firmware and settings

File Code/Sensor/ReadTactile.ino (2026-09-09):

/*
MPL3115A2 Barometric Pressure Sensor Array
This sketch reads the pressure from 16 MPL3115A2 sensors

Hardware:
Arduino Uno
  -VCC = 3.3V
  -SDA = SDA
  -SCL = SCL
  -GND = GND
  -INT1 = not connected
  -INT2 = not connected
  -s0, s1, s2, s3 connected to digital pins 2, 3, 4, 5

Serial terminal at 9600bps
*/

#include <Wire.h> // for IIC communication
#include <Arduino.h>

// input pins for mux
int s0 = 2;
int s1 = 3;
int s2 = 4;
int s3 = 5;

// sensor number
// const int sensorNum = 16;
const int sensorNum = 16;
float pressureValues[sensorNum];
float tempValues[sensorNum];


int time_inter = 10; //time period btw switching
int t2 = millis();
int t1;

// position
int pos = 0;

int muxChannel[16][4] =
{
  {0, 0, 0, 0}, //channel 0
  {1, 0, 0, 0}, //channel 1
  {0, 1, 0, 0}, //channel 2
  {1, 1, 0, 0}, //channel 3
  {0, 0, 1, 0}, //channel 4
  {1, 0, 1, 0}, //channel 5
  {0, 1, 1, 0}, //channel 6
  {1, 1, 1, 0}, //channel 7
  {0, 0, 0, 1}, //channel 8
  {1, 0, 0, 1}, //channel 9
  {0, 1, 0, 1}, //channel 10
  {1, 1, 0, 1}, //channel 11
  {0, 0, 1, 1}, //channel 12
  {1, 0, 1, 1}, //channel 13
  {0, 1, 1, 1}, //channel 14
  {1, 1, 1, 1} //channel 15
}; 

#define STATUS     0x00
#define OUT_P_MSB  0x01
#define OUT_P_CSB  0x02
#define OUT_P_LSB  0x03
#define OUT_T_MSB  0x04
#define OUT_T_LSB  0x05
#define DR_STATUS  0x06
#define OUT_P_DELTA_MSB  0x07
#define OUT_P_DELTA_CSB  0x08
#define OUT_P_DELTA_LSB  0x09
#define OUT_T_DELTA_MSB  0x0A
#define OUT_T_DELTA_LSB  0x0B
#define WHO_AM_I   0x0C
#define F_STATUS   0x0D
#define F_DATA     0x0E
#define F_SETUP    0x0F
#define TIME_DLY   0x10
#define SYSMOD     0x11
#define INT_SOURCE 0x12
#define PT_DATA_CFG 0x13
#define BAR_IN_MSB 0x14
#define BAR_IN_LSB 0x15
#define P_TGT_MSB  0x16
#define P_TGT_LSB  0x17
#define T_TGT      0x18
#define P_WND_MSB  0x19
#define P_WND_LSB  0x1A
#define T_WND      0x1B
#define P_MIN_MSB  0x1C
#define P_MIN_CSB  0x1D
#define P_MIN_LSB  0x1E
#define T_MIN_MSB  0x1F
#define T_MIN_LSB  0x20
#define P_MAX_MSB  0x21
#define P_MAX_CSB  0x22
#define P_MAX_LSB  0x23
#define T_MAX_MSB  0x24
#define T_MAX_LSB  0x25
#define CTRL_REG1  0x26
#define CTRL_REG2  0x27
#define CTRL_REG3  0x28
#define CTRL_REG4  0x29
#define CTRL_REG5  0x2A
#define OFF_P      0x2B
#define OFF_T      0x2C
#define OFF_H      0x2D

#define MPL3115A2_ADDRESS 0x60 // 7-bit I2C address


void setup()
{
  char incomingByte;
  Wire.begin();        // join i2c bus
  Serial.begin(115200);  // start serial for output
  pinMode(s0, OUTPUT);
  pinMode(s1, OUTPUT);
  pinMode(s2, OUTPUT);
  pinMode(s3, OUTPUT);
  

  // Configure the sensor
  for (int i = 0; i < sensorNum; i ++)
  {
    setChannel(i);
    if(IIC_Read(WHO_AM_I) == 196){
      Serial.print("Checking Sensor");Serial.println(i);
    }
    else{
      Serial.print("Sensor");Serial.print(i);
      Serial.println(" No response - check connections");
    }
    if(IIC_Read(WHO_AM_I) == 196){
      Serial.print("Sensor");Serial.print(i);
      Serial.println(" MPL3115A2 online!");
    }
    else{
      Serial.print("Sensor");Serial.print(i);
      Serial.println(" No response - check connections");
    }
    setModeBarometer(); // Measure pressure in Pascals from 20 to 110 kPa
    setOversampleRate(5); // Set Oversample to the recommended 128
    enableEventFlags(); // Enable all three pressure and temp event flags
    delay(200);
  }
  Serial.println("Done");
  

}

void loop()
{
  // Read pressure
  for (int i = 0; i < 16; i ++)
  {
    readPressureMux(i);
  }
  // delay(100);

  // if serial input available, save to variable
  for (int i = 0; i < 16; i ++){
      Serial.print(pressureValues[i]);Serial.print(" ");
  }Serial.println();
}

//Returns the number of meters above sea level
float readAltitude()
{
  toggleOneShot(); //Toggle the OST bit causing the sensor to immediately take another reading

  //Wait for PDR bit, indicates we have new pressure data
  int counter = 0;
  while( (IIC_Read(STATUS) & (1<<1)) == 0)
  {
      if(++counter > 100) return(-999); //Error out
      delay(1);
  }
  
  // Read pressure registers
  Wire.beginTransmission(MPL3115A2_ADDRESS);
  Wire.write(OUT_P_MSB);  // Address of data to get
  Wire.endTransmission(false); // Send data to I2C dev with option for a repeated start. THIS IS NECESSARY and not supported before Arduino V1.0.1!
  Wire.requestFrom(MPL3115A2_ADDRESS, 3); // Request three bytes

  //Wait for data to become available
  counter = 0;
  while(Wire.available() < 3)
  {
    if(counter++ > 100) return(-999); //Error out
    delay(1);
  }

  byte msb, csb, lsb;
  msb = Wire.read();
  csb = Wire.read();
  lsb = Wire.read();

  toggleOneShot(); //Toggle the OST bit causing the sensor to immediately take another reading

  float tempcsb = (lsb>>4)/16.0;

  float altitude = (float)( (msb << 8) | csb) + tempcsb;

  return(altitude);
}

//Returns the number of feet above sea level
float readAltitudeFt()
{
  return(readAltitude() * 3.28084);
}

//Reads the current pressure in Pa
//Unit must be set in barometric pressure mode
float readPressure()
{
  toggleOneShot(); //Toggle the OST bit causing the sensor to immediately take another reading

  //Wait for PDR bit, indicates we have new pressure data
  int counter = 0;
  while( (IIC_Read(STATUS) & (1<<2)) == 0)
  {
      if(++counter > 100) return(-999); //Error out
      delay(1);
  }

  // Read pressure registers
  Wire.beginTransmission(MPL3115A2_ADDRESS);
  Wire.write(OUT_P_MSB);  // Address of data to get
  Wire.endTransmission(false); // Send data to I2C dev with option for a repeated start. THIS IS NECESSARY and not supported before Arduino V1.0.1!
  Wire.requestFrom(MPL3115A2_ADDRESS, 3); // Request three bytes

  //Wait for data to become available
  counter = 0;
  while(Wire.available() < 3)
  {
    if(counter++ > 100) return(-999); //Error out
    delay(1);
  }

  byte msb, csb, lsb;
  msb = Wire.read();
  csb = Wire.read();
  lsb = Wire.read();

  toggleOneShot(); //Toggle the OST bit causing the sensor to immediately take another reading

  // Pressure comes back as a left shifted 20 bit number
  long pressure_whole = (long)msb<<16 | (long)csb<<8 | (long)lsb;
  pressure_whole >>= 6; //Pressure is an 18 bit number with 2 bits of decimal. Get rid of decimal portion.

  lsb &= 0b00110000; //Bits 5/4 represent the fractional component
  lsb >>= 4; //Get it right aligned
  float pressure_decimal = (float)lsb/4.0; //Turn it into fraction

  float pressure = (float)pressure_whole + pressure_decimal;

  return(pressure);
}

float readTemp()
{
  toggleOneShot(); //Toggle the OST bit causing the sensor to immediately take another reading

  //Wait for TDR bit, indicates we have new temp data
  int counter = 0;
  while( (IIC_Read(STATUS) & (1<<1)) == 0)
  {
      if(++counter > 100) return(-999); //Error out
      delay(1);
  }
  
  // Read temperature registers
  Wire.beginTransmission(MPL3115A2_ADDRESS);
  Wire.write(OUT_T_MSB);  // Address of data to get
  Wire.endTransmission(false); // Send data to I2C dev with option for a repeated start. THIS IS NECESSARY and not supported before Arduino V1.0.1!
  Wire.requestFrom(MPL3115A2_ADDRESS, 2); // Request two bytes

  //Wait for data to become available
  counter = 0;
  while(Wire.available() < 2)
  {
    if(++counter > 100) return(-999); //Error out
    delay(1);
  }

  byte msb, lsb;
  msb = Wire.read();
  lsb = Wire.read();
  
  // The least significant bytes l_altitude and l_temp are 4-bit,
  // fractional values, so you must cast the calulation in (float),
  // shift the value over 4 spots to the right and divide by 16 (since 
  // there are 16 values in 4-bits). 
  float templsb = (lsb>>4)/16.0; //temp, fraction of a degree

  float temperature = (float)(msb + templsb);

  return(temperature);
}

//Give me temperature in fahrenheit!
float readTempF()
{
  return((readTemp() * 9.0)/ 5.0 + 32.0); // Convert celsius to fahrenheit
}

//Sets the mode to Barometer
//CTRL_REG1, ALT bit
void setModeBarometer()
{
  byte tempSetting = IIC_Read(CTRL_REG1); //Read current settings
  tempSetting &= ~(1<<7); //Clear ALT bit
  IIC_Write(CTRL_REG1, tempSetting);
}

//Sets the mode to Altimeter
//CTRL_REG1, ALT bit
void setModeAltimeter()
{
  byte tempSetting = IIC_Read(CTRL_REG1); //Read current settings
  tempSetting |= (1<<7); //Set ALT bit
  IIC_Write(CTRL_REG1, tempSetting);
}

//Puts the sensor in standby mode
//This is needed so that we can modify the major control registers
void setModeStandby()
{
  byte tempSetting = IIC_Read(CTRL_REG1); //Read current settings
  tempSetting &= ~(1<<0); //Clear SBYB bit for Standby mode
  IIC_Write(CTRL_REG1, tempSetting);
}

//Puts the sensor in active mode
//This is needed so that we can modify the major control registers
void setModeActive()
{
  byte tempSetting = IIC_Read(CTRL_REG1); //Read current settings
  tempSetting |= (1<<0); //Set SBYB bit for Active mode
  IIC_Write(CTRL_REG1, tempSetting);
}

//Setup FIFO mode to one of three modes. See page 26, table 31
//From user jr4284
void setFIFOMode(byte f_Mode)
{
  if (f_Mode > 3) f_Mode = 3; // FIFO value cannot exceed 3.
  f_Mode <<= 6; // Shift FIFO byte left 6 to put it in bits 6, 7.

  byte tempSetting = IIC_Read(F_SETUP); //Read current settings
  tempSetting &= ~(3<<6); // clear bits 6, 7
  tempSetting |= f_Mode; //Mask in new FIFO bits
  IIC_Write(F_SETUP, tempSetting);
}

//Call with a rate from 0 to 7. See page 33 for table of ratios.
//Sets the over sample rate. Datasheet calls for 128 but you can set it 
//from 1 to 128 samples. The higher the oversample rate the greater
//the time between data samples.
void setOversampleRate(byte sampleRate)
{
  if(sampleRate > 7) sampleRate = 7; //OS cannot be larger than 0b.0111
  sampleRate <<= 3; //Align it for the CTRL_REG1 register

  byte tempSetting = IIC_Read(CTRL_REG1); //Read current settings
  tempSetting &= 0b11000111; //Clear out old OS bits
  tempSetting |= sampleRate; //Mask in new OS bits
  IIC_Write(CTRL_REG1, tempSetting);
}

//Clears then sets the OST bit which causes the sensor to immediately take another reading
//Needed to sample faster than 1Hz
void toggleOneShot(void)
{
  byte tempSetting = IIC_Read(CTRL_REG1); //Read current settings
  tempSetting &= ~(1<<1); //Clear OST bit
  IIC_Write(CTRL_REG1, tempSetting);

  tempSetting = IIC_Read(CTRL_REG1); //Read current settings to be safe
  tempSetting |= (1<<1); //Set OST bit
  IIC_Write(CTRL_REG1, tempSetting);
}

//Enables the pressure and temp measurement event flags so that we can
//test against them. This is recommended in datasheet during setup.
void enableEventFlags()
{
  IIC_Write(PT_DATA_CFG, 0x07); // Enable all three pressure and temp event flags 
}

// These are the two I2C functions in this sketch.
byte IIC_Read(byte regAddr)
{
  // This function reads one byte over IIC
  Wire.beginTransmission(MPL3115A2_ADDRESS);
  Wire.write(regAddr);  // Address of CTRL_REG1
  Wire.endTransmission(false); // Send data to I2C dev with option for a repeated start. THIS IS NECESSARY and not supported before Arduino V1.0.1!
  Wire.requestFrom(MPL3115A2_ADDRESS, 1); // Request the data...
  return Wire.read();
}

void IIC_Write(byte regAddr, byte value)
{
  // This function writes one byto over IIC
  Wire.beginTransmission(MPL3115A2_ADDRESS);
  Wire.write(regAddr);
  Wire.write(value);
  Wire.endTransmission(true);
}

// set channel
void setChannel(int channel)
{
  int controlPin[] = {s0, s1, s2, s3};
  // loop through the 4 sig
  for (int i = 0; i < 4; i ++)
  {
    digitalWrite(controlPin[i], muxChannel[channel][i]);
  }
  return 0;
}


// Read pressure
void readPressureMux(int channel)
{
  setChannel(channel);
  pressureValues[channel] = readPressure();
  // t1 = millis();
  // Serial.print(" time diff:");
  // Serial.print(t1 - t2);
  // Serial.println();
  // t2 = t1;
  // delay(time_inter);
}

// Read temperature
void readTempMux(int channel)
{
  setChannel(channel);
  // Serial.print("Sensor "); Serial.println(channel);
  tempValues[channel] = readTemp();
  // Serial.print(" Temperature(C):");
  // Serial.println(tempValues[channel], 2);
}

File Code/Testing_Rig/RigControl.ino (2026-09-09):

#include <EEPROM.h>

//X:
#define dirPin 2
#define stepPin 3
#define limitSwitchPin 10

//Z:
#define dirPinZ 9
#define stepPinZ 8
#define stepsPerRevolution 500
#define stepDelay 600
#define mmToStep 1000
#define ZmmToStep 480

// variable for data collection
int z_impulse_period = 1000; // microsec
// int z_impulse_period = 500; // microsec
// int z_impulse_period = 3000; // microsec
int t_waiting = 16000; // millisec
// int t_waiting = 20000; // millisec
// int t_waiting = 0; // millisec

int homingState = 0;
bool isReturningFromHoming = false;
bool isHomingZ = true;
unsigned long stateChangeTime = 0;
int homingPulseDelay = 50;

long stepCount = 0;
long stepTarget = 0;
long ZstepCount = 0;
long ZstepTarget = 0;
int stepMultiplier = 1; //for step to mm conversion in X
int ZstepMultiplier = 1; //for step to mm conversion in Z
bool isSetHome = true; //distinguish between going home and setting home
bool isGoingLeft = true; //for homing
bool isGoingDown = true; 
unsigned long homeStepCounter = 0;
//unsigned long zStepCounter = 0;
long absolutePos = 0;
long absolutePosZ = 0;




//******
//Driver takes pulse widths no lower than 2.5 microseconds
//dirPin HIGH -> moving away from stepper
//screw pitch 5mm

//Homing States:
//0 - idle
//1 - homing requested
//******

String in_chars = "";


void setup() {

  pinMode(stepPinZ, OUTPUT);
  pinMode(dirPinZ, OUTPUT);

  pinMode(stepPin, OUTPUT);
  pinMode(dirPin, OUTPUT);
  pinMode(limitSwitchPin, INPUT);

  homingState = 0;



  Serial.begin(115200);
  delay(100);
  Serial.println("");
  Serial.println("");

  Serial.println("------Commands:----------------");
  Serial.println("st+X  (move X steps to the right)");
  Serial.println("st-X  (move X steps to the left)");
  Serial.println("mm+X  (move X millimetres to the right)");
  Serial.println("mm-X  (move X millimetres to the left)");
  Serial.println("setHome  (set current position as home)");
  Serial.println("home  (go to home)");
  Serial.println("zst+X  (move X steps down)");
  Serial.println("zst-X  (move X steps up)");
  Serial.println("zmm+X  (move X millimetres down)");
  Serial.println("zmm-X  (move X millimetres up)");
  Serial.println("zhome  (pull up Z acuator to the limit)");
  Serial.println("-------------------------------");

}

void loop() {
  readSerialCommand();

  if (stepCount < stepTarget && !homingState) {
    delayMicroseconds(50);
    digitalWrite(stepPin, HIGH);
    delayMicroseconds(50);
    digitalWrite(stepPin, LOW);
    stepCount++;
    
    if (isGoingLeft){
      absolutePos--;
    }else{
      absolutePos++;
    }

    if (!(absolutePos % 10) && !isReturningFromHoming){
      Serial.println('x' + String(-absolutePos));
    }
    
    if (stepCount == stepTarget) {
      delay(1000);
      Serial.println("Done");
      Serial.println("-------------------------");
      isReturningFromHoming = false;
      
    }
  }

  if (ZstepCount < ZstepTarget && !homingState) {
    delayMicroseconds(z_impulse_period);
    digitalWrite(stepPinZ, HIGH);
    delayMicroseconds(z_impulse_period);
    digitalWrite(stepPinZ, LOW);
    ZstepCount++;

    if (isGoingDown){
      absolutePosZ++;
    }else{
      absolutePosZ--;
    }

    if (!(absolutePosZ % 6) && !isHomingZ){
      Serial.println(String('z') + String('p') + String(absolutePosZ));
    }
    if (ZstepCount == ZstepTarget) {
      if (isGoingDown){
        delay(t_waiting);
      }
      Serial.println("Done");
      Serial.println("-------------------------");
      if (isHomingZ){
        absolutePosZ = 0;
      }
      isHomingZ = false;
    }
  }

  if (homingState) {
    isReturningFromHoming = true;
    delayMicroseconds(homingPulseDelay);
    digitalWrite(stepPin, HIGH);
    delayMicroseconds(homingPulseDelay);
    digitalWrite(stepPin, LOW);

    if (isSetHome) {
      if (isGoingLeft) {
        homeStepCounter++;
      } else {
        homeStepCounter--;
      }
    }

    //state changes:
    if (homingState == 1 && digitalRead(limitSwitchPin)) {
      //hit switch first time
      homingState = 2;
      //      Serial.println("state 2");
      homingPulseDelay = 300;
      digitalWrite(dirPin, HIGH);
      isGoingLeft = false;
      stateChangeTime = millis();
      //      Serial.println(stateChangeTime);
      delayMicroseconds(500);
    } else if (homingState == 2 && (millis() - stateChangeTime >= 1000)) {
      homingState = 3;
      //      Serial.println("state 3");
      //      Serial.println(millis()-stateChangeTime);
      homingPulseDelay = 1000;
      digitalWrite(dirPin, LOW);
      isGoingLeft = true;

      stateChangeTime = millis();

    } else if (homingState == 3 && digitalRead(limitSwitchPin) == 1 && millis() - stateChangeTime >= 500) {

      if (isSetHome) {
        EEPROM.put(0, homeStepCounter);
      }

      homingState = 0;
      
      //return to home
      digitalWrite(dirPin, HIGH);
      isGoingLeft = false;

      stepCount = 0;
      EEPROM.get(0, stepTarget);
      absolutePos = -stepTarget;
      //      Serial.println(homeStepCounter);
      //      Serial.println(stepTarget);

    }

  }

//  TEST:Loop Z

//  digitalWrite(dirPinZ, zDir);
//
//  digitalWrite(stepPinZ, HIGH);
//  delayMicroseconds(stepDelay);
//  digitalWrite(stepPinZ, LOW);
//  delayMicroseconds(stepDelay);
//  zStepCounter++;
//
//  if (zStepCounter >=  2000){
//    zStepCounter = 0;
//    zDir = !zDir;
//  }



}


void moveStepperFromSerial() {
  if (in_chars[2] == '+' || in_chars[2] == '-') {
    digitalWrite(dirPin, in_chars[2] == '+'); //HIGH if 3rd char is '+'
    isGoingLeft =  in_chars[2] == '-';
    char *dist = &in_chars[3]; //eliminate first two chars
    dist[strlen(dist) - 1] = '\0'; //eliminate \n
    //    Serial.println(atof(dist)*stepMultiplier);
    stepTarget = atof(dist) * stepMultiplier;
    Serial.print("moving [");
    Serial.print(in_chars[2]);
    Serial.print(stepTarget);
    Serial.println("] steps in X...");
    if (stepTarget) {
//      Serial.println("running...");
      stepCount = 0;
    } else {
      Serial.println("[invalid step count!]");
    }
  } else {
    Serial.println("[invalid command!]");
  }
}

void moveZStepperFromSerial() {
  if (in_chars[3] == '+' || in_chars[3] == '-') {
    digitalWrite(dirPinZ, in_chars[3] == '+'); //HIGH if 3rd char is '+'
    isGoingDown = in_chars[3] == '+';
    char *dist = &in_chars[4]; //eliminate first three chars
    dist[strlen(dist) - 1] = '\0'; //eliminate \n
    //    Serial.println(atof(dist)*stepMultiplier);
    ZstepTarget = atof(dist) * ZstepMultiplier;
    Serial.print("moving [");
    Serial.print(in_chars[3]);
    Serial.print(ZstepTarget);
    Serial.println("] steps in Z...");
    if (ZstepTarget) {
//      Serial.println("running...");
      ZstepCount = 0;
    } else {
      Serial.println("[invalid step count!]");
    }
  } else {
    Serial.println("[invalid command!]");
  }
}
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
